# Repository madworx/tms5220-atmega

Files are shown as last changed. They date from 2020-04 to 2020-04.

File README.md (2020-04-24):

# TMS5220 Exploration unit

This project was created to try out the Texas Instruments TMS5220 _Voice synthesis processor_ (of TI99/4A, Apple II Echo 2, and various pinball/arcade games fame).

First off, a word of warning: The PCB being powered by potentially three sources (PSU, Communication USB, AVR ISP), I've observed some weird behavior with power unexpectedly flowing in the wrong direction, causing intermittent system interruptions, host USB-port lock-up requiring system restart and one burnt MCU.

Preferably disconnect the PSU before connecting the ISP and move the `J3` jumper to programming mode.

The project as it currently is is rather "build your own" but since the project was created to let me toy with the TMS5220 chip, it's not likely to see any major improvements in the forseeable future.

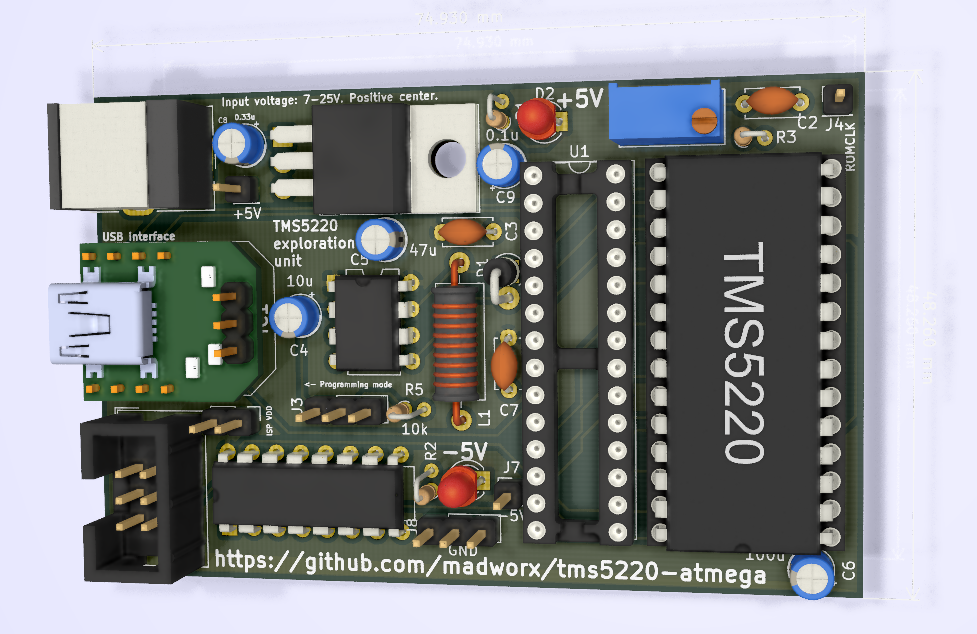
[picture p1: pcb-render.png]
PCB rendering


## Software environment

* `avrdude`
* `avr-gcc`

## Peripherials setup

### Programmer (AVR ISP)

I used a cheap `usbasp` clone.

### UB232R

The `UB232R` interface needs to be configured using the [FT_Prog] tool:

* `High Current I/O's` to be disabled.

* Under the `IO Controls` section, output on pin `C0` should be set to `CLK12`, providing the Atmega 328P with a system clock of 12MHz.

The baud rate is the USB interface is configured by the host operating system driver. The MCU UART baud rate need to be matched to this.

[FT_Prog]: https://www.ftdichip.com/Support/Utilities.htm#FT_PROG

### Atmega 328P

* `lfuse` should be programmed to _external clock without /8DIV_ (`0xE0`):

```
avrdude -p m328p -c usbasp -U lfuse:w:0xE0:m
```

## TMS5220 details

### D/A

10-bit twos-complement.

```
|           |  PC latice outputs                                      |            |             |
|-----------|---------------------------------------------------------|------------|-------------|
| Value     |  YD  YC  YB  YA  Y9  Y8  Y7  Y6  Y5  Y4  Y3  Y2  Y1  Y0 | D/A input  | Analog (uA) |
|-----------|---------------------------------------------------------|------------|-------------|
| > +127    |  0   1   1   x   x   x   x   x   x   x   x   x   x   x  |  11111111  |      0      |
| > +127    |  0   1   0   x   x   x   x   x   x   x   x   x   x   x  |  11111111  |      0      |
| > +127    |  0   0   1   x   x   x   x   x   x   x   x   x   x   x  |  11111111  |      0      |
| +127      |  0   0   0   1   1   1   1   1   1   1   1   x   x   x  |  11111111  |      0      |
| +126      |  0   0   0   1   1   1   1   1   1   1   0   x   x   x  |  11111110  |      5.86   |
| etc.      |  0   0   0   .   .   .   .   .   .   .   .   x   x   x  |  ........  |     .....   |
| +1        |  0   0   0   0   0   0   0   0   0   0   1   x   x   x  |  10000001  |    738.00   |
| 0         |  0   0   0   0   0   0   0   0   0   0   0   x   x   x  |  10000000  |    744.00   |
| -1 (off)  |  1   1   1   1   1   1   1   1   1   1   1   x   x   x  |  01111111  |    750.00   |
| -2        |  1   1   1   1   1   1   1   1   1   1   0   x   x   x  |  01111110  |    755.80   |
| etc.      |  1   1   1   .   .   .   .   .   .   .   .   x   x   x  |  ........  |   .......   |
| -128      |  1   1   1   0   0   0   0   0   0   0   0   x   x   x  |  00000000  |   1500.00   |
| < -128    |  1   1   0   x   x   x   x   x   x   x   x   x   x   x  |  00000000  |   1500.00   |
| < -128    |  1   0   1   x   x   x   x   x   x   x   x   x   x   x  |  00000000  |   1500.00   |
| < -128    |  1   0   0   x   x   x   x   x   x   x   x   x   x   x  |  00000000  |   1500.00   |
```

### Timing diagram

* `ROMCLK` = 160kHz (= 6,26uS = 75x 12MHz cycles -> 37.5 cycles per level):
* `T11` is pulled high before the start of each 10-bit word. (Note: The `T11`/`IO` cycle will run as long as the TMS chip is powered, regardless if any `SPEAK` or `SPEAK EXTERNAL` commands are currently running or not.)

```
 | 36| 36| 36| Clock cycles @ 12MHz

                             |
  ___     ___     ___     ___v    ___     ___     ___     ___     ___     ___     ___     ___     ___     
_|   |___|   |___|   |___|   |___|   |___|   |___|   |___|   |___|   |___|   |___|   |___|   |___|   |___|   *ROMCLK*
          _______            :
_________|       |___________:____________________________________________________________________________   *T11*
                          ___:___________________________________________________________________________
_________________________|  lsb  |       |       |       |       |       |       |       |       |  msb  |   *I/O*
                             ^
                             |
                             +-- This is where we sample & store the value of I/O.
```

## Code structure 

* TMS5220 flag us that it's ready to receive data with the use of the `~READY` signal.

* On negative edge trigger: Sample I/O pin, shift storage byte and add bit. (This should be in the range of ~15 instructions)

* On positive edge trigger: Perform state-based logic (max ~35 clock cycles to complete each operation).

* A full write of `DBUS` on the TMS requires us to write to three different ports on the Atmega. (~15 instructions each)

## Accessing the USB UART under linux with 250000 baud rate

```
 $ setserial -a /dev/ttyUSB0 spd_cust
 $ setserial -a /dev/ttyUSB0 divisor 64 # for 375000
 $ setserial -a /dev/ttyUSB0 divisor 96 # for 250000
 $ stty -F /dev/ttyUSB0 38400
 $ socat TCP-L:1147 FILE:/dev/ttyUSB0,b38400,raw,echo=0
```

## Afterthoughts on PCB design

* Atmega reset button on PCB would be nice.
* Proximity to other components makes the jumpers hard to access.
* Should have used a trimmer with lower resistance and a base resistor of higher value to enable more accurate tuning of `ROMCLK`.
* Possibly some form of "mode switch" to select different functions in the MCU.
* Could likely have been powered by USB directly, eliminating the external PSU. (However, need to take into account that +5 and -5V needs to be applied more or less simultaneous)
* Hard to dislodge the TMS chip due to resistor in the way.
* Bottom mounting of TMS resistor on PCB due to placement near socket edge -- has been fixed in current PCB layout, but not in manufactured ones.
* Hard to dislodge Atmega328P due to resistor in the way -- has been fixed in current PCB layout, but not in manufactured ones.
* A status LED or two would be nice.
* Reading more about the TMS chip, I could have driven the "TESTING USE ONLY" `PROMOUT` pin to -5 to enable external clocking, removing timing constraints for the MCU.
* The "programming mode" jumper in the end turned out quite useless -- a proper RESET of the TMS-chip usually cleared up any inconsistencies.
* Multiple pins connected to TMS5220 that in the end weren't needed.
* Power drainage is much higher than expected; Around 500mA and LM7805 reaches 51 degrees C.

## Oscillator caps

### TMS5220 T11, ROMCLK, IO

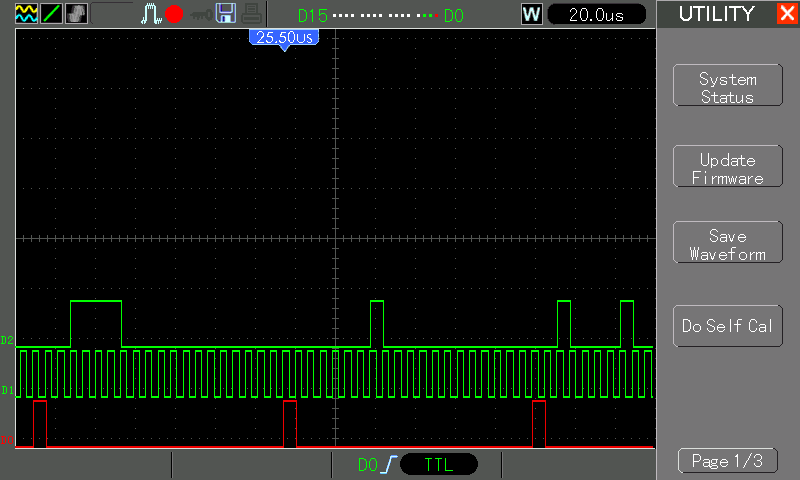
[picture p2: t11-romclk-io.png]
TMS5220 T11, ROMCLK, IO


### TMS5220 ROMCLK output

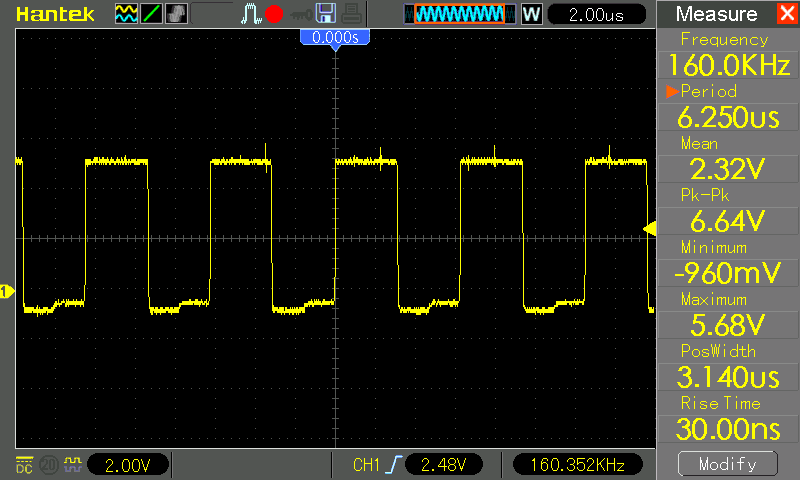
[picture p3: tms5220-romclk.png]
TMS5220 ROMCLK output


### UB232R-CLK12

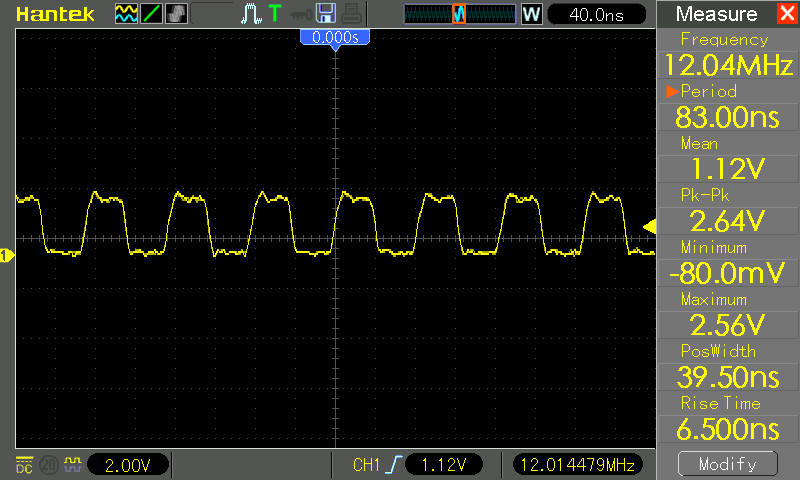
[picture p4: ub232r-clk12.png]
ub232r-clk12


Connected to Atmega328P:

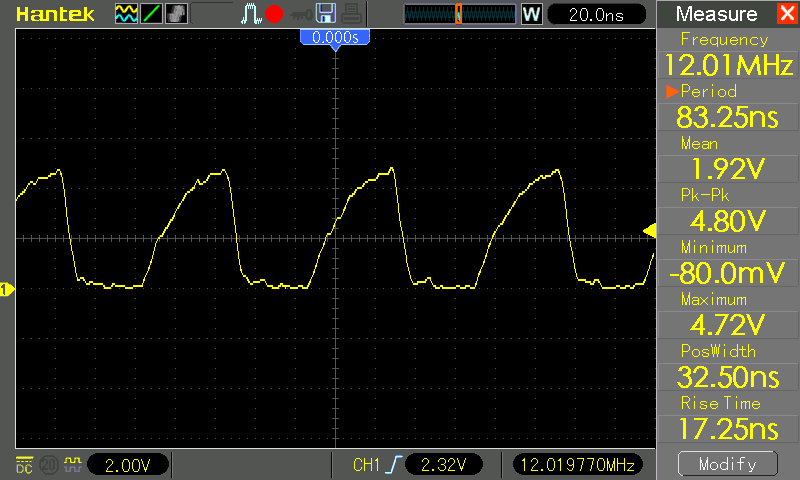
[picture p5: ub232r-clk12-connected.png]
ub232r-clk12-connected


## References

* [TMS5220 Data sheet PDF](references/tms5220.pdf)
* [TMS5220 reference from www.unige.ch](http://www.unige.ch/medecine/nouspikel/ti99/speech.htm)

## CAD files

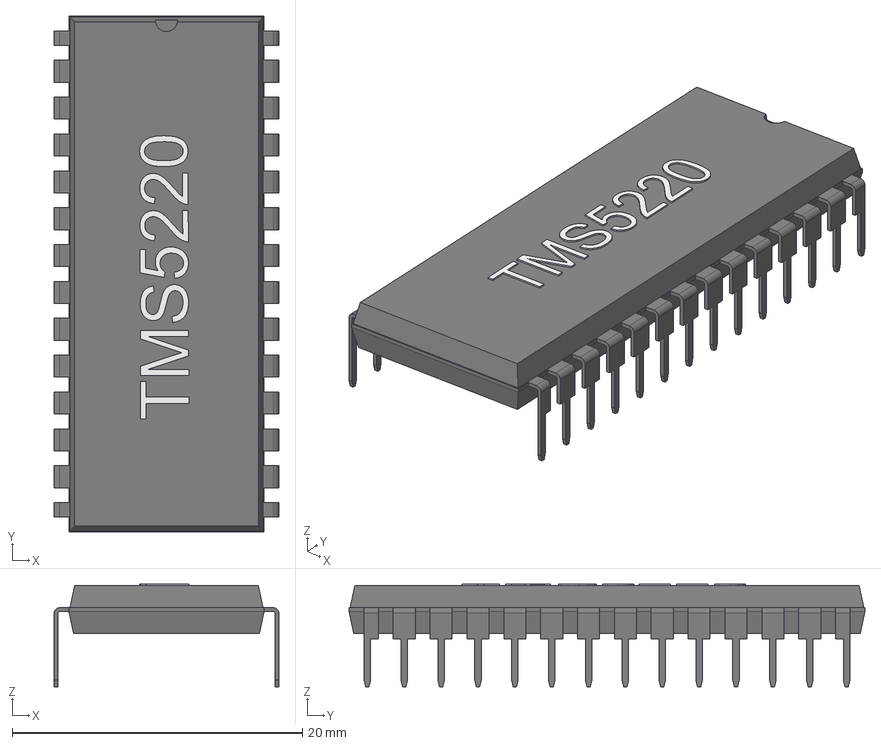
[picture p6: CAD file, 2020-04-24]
hardware/components/TMS5220.FCStd
15.5 x 35.6 x 7.08 mm
DIP-28_W15.24mm

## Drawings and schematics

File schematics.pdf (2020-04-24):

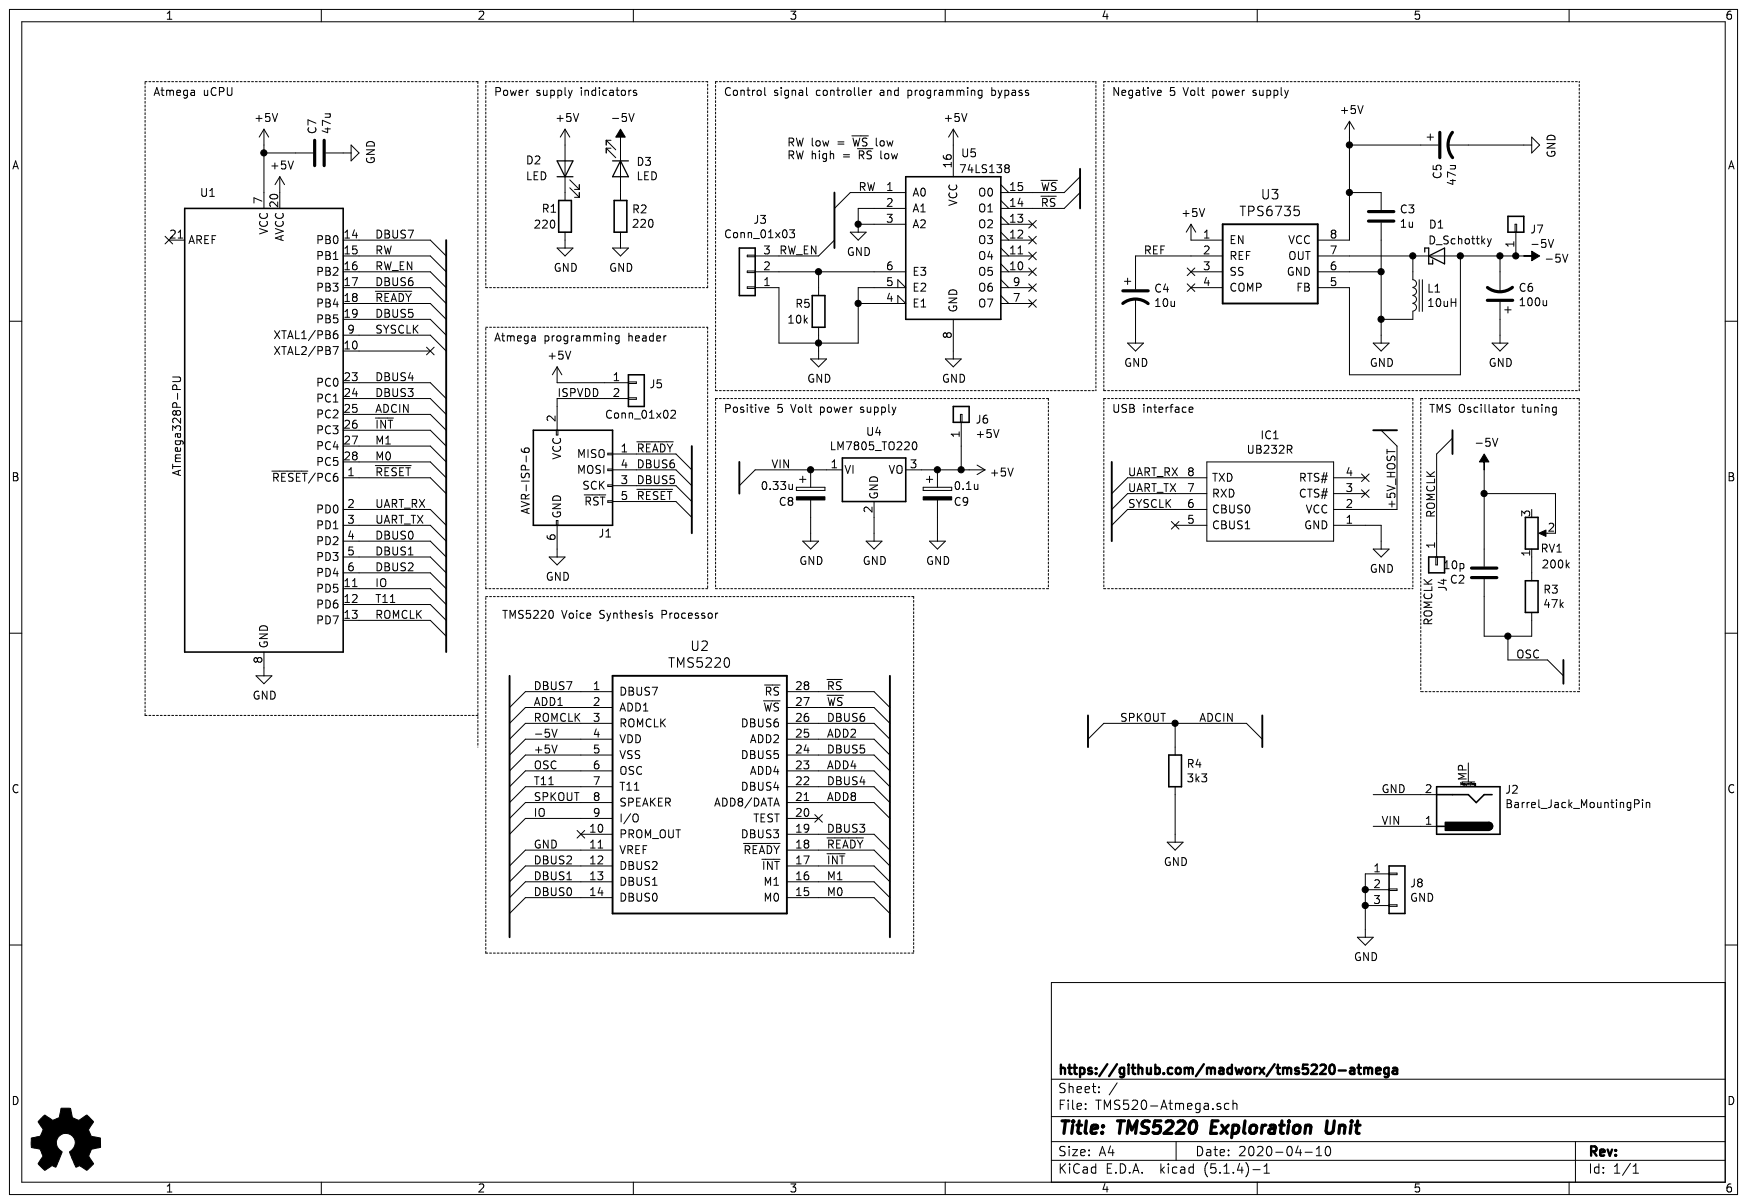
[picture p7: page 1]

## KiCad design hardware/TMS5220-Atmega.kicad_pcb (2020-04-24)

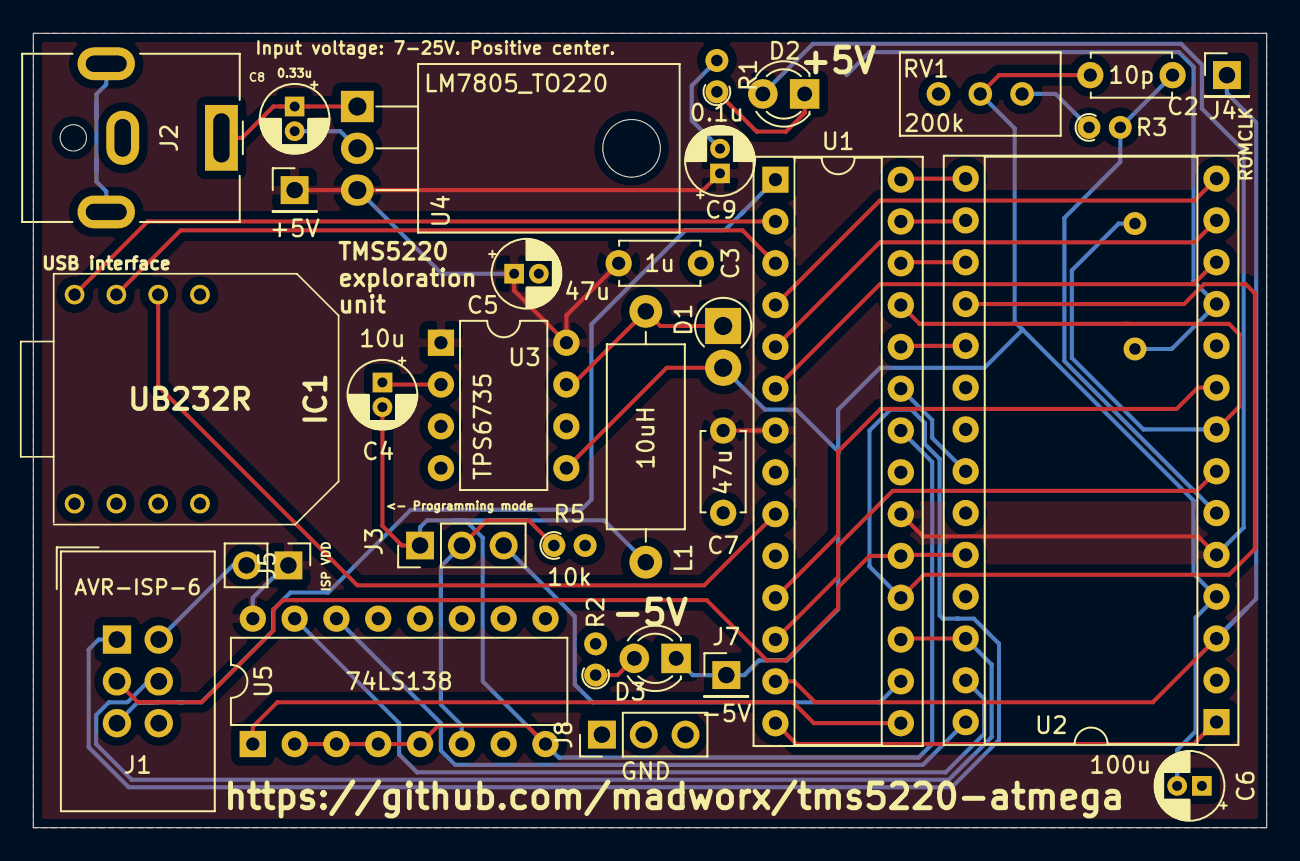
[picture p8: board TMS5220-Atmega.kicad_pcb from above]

Board: 2 copper layers, 74.9 x 48.3 mm, 32 parts (1 on the bottom side), 36 nets.

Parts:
C2: 10p; C_Disc_D4.7mm_W2.5mm_P5.00mm
C3: 1u; C_Disc_D4.7mm_W2.5mm_P5.00mm
C4: 10u; CP_Radial_D4.0mm_P1.50mm
C5: 47u; CP_Radial_D4.0mm_P1.50mm
C6: 100u; CP_Radial_D4.0mm_P1.50mm
C7: 47u; C_Disc_D4.7mm_W2.5mm_P5.00mm
C8: 0.33u; CP_Radial_D4.0mm_P1.50mm
C9: 0.1u; CP_Radial_D4.0mm_P1.50mm
D1: D_Schottky; D_DO-41_SOD81_P2.54mm_Vertical_AnodeUp
D2, D3: LED; LED_D3.0mm
IC1: UB232R
J1: AVR-ISP-6; IDC-Header_2x03_P2.54mm_Vertical
J2: Barrel_Jack_MountingPin; BarrelJack_CUI_PJ-063AH_Horizontal
J3: Conn_01x03; PinHeader_1x03_P2.54mm_Vertical
J4: ROMCLK; PinHeader_1x01_P2.54mm_Vertical
J5: Conn_01x02; PinHeader_1x02_P2.54mm_Vertical
J6: +5V; PinHeader_1x01_P2.54mm_Vertical
J7: -5V; PinHeader_1x01_P2.54mm_Vertical
J8: GND; PinHeader_1x03_P2.54mm_Vertical
L1: 10uH; L_Axial_L11.0mm_D4.5mm_P15.24mm_Horizontal_Fastron_MECC
R1, R2: 220; R_Axial_DIN0204_L3.6mm_D1.6mm_P1.90mm_Vertical
R3: 47k; R_Axial_DIN0204_L3.6mm_D1.6mm_P1.90mm_Vertical
R4: 3k3; R_Axial_DIN0204_L3.6mm_D1.6mm_P7.62mm_Horizontal
R5: 10k; R_Axial_DIN0204_L3.6mm_D1.6mm_P1.90mm_Vertical
RV1: 200k; Potentiometer_Bourns_3296W_Vertical
U1: ATmega328P-PU; DIP-28_W7.62mm_Socket
U2: TMS5220; DIP-28_W15.24mm_Socket
U3: TPS6735; DIP-8_W7.62mm
U4: LM7805_TO220; TO-220-3_Horizontal_TabDown
U5: 74LS138; DIP-16_W7.62mm

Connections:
+5V: C3.1, C5.1, C7.1, C9.1, D2.2, J5.1, J6.1, U1.7, U1.20, U2.5, U3.1, U3.8, U4.3, U5.16
-5V: C2.2, C6.2, D1.2, D3.1, J7.1, RV1.2, U2.4, U3.5
/ADCIN: R4.1, U1.25, U2.8
/DBUS0: U1.4, U2.14
/DBUS1: U1.5, U2.13
/DBUS2: U1.6, U2.12
/DBUS3: U1.24, U2.19
/DBUS4: U1.23, U2.22
/DBUS5: J1.3, U1.19, U2.24
/DBUS6: J1.4, U1.17, U2.26
/DBUS7: U1.14, U2.1
/IO: U1.11, U2.9
/ISPVDD: J1.2, J5.2
/M0: U1.28, U2.15
/M1: U1.27, U2.16
/OSC: C2.1, R3.2, U2.6
/REF: C4.1, U3.2
/ROMCLK: J4.1, U1.13, U2.3
/RW: U1.15, U5.1
/RW_EN: J3.3, U1.16
/SYSCLK: IC1.6, U1.9
/T11: U1.12, U2.7
/UART_RX: IC1.8, U1.2
/UART_TX: IC1.7, U1.3
/VIN: C8.1, J2.1, U4.1
/~INT: U1.26, U2.17
/~READY: J1.1, U1.18, U2.18
/~RESET: J1.5, U1.1
/~RS: U2.28, U5.14
/~WS: U2.27, U5.15
GND: C3.2, C4.2, C5.2, C6.1, C7.2, C8.2, C9.2, IC1.1, J1.6, J2.2, J3.1, J8.1, J8.2, J8.3, L1.2, R1.2, R2.2, R4.2, R5.2, U1.8, U1.22, U2.11, U3.6, U4.2, U5.2, U5.3, U5.4, U5.5, U5.8
unnamed: D1.1, L1.1, U3.7
unnamed: D2.1, R1.1
unnamed: D3.2, R2.1
unnamed: J3.2, R5.1, U5.6
unnamed: R3.1, RV1.1

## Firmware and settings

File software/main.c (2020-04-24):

#define F_CPU 12000000      /* 12 MHz */
#define BAUD    250000      /* 250'000 baud */

#define READY    PB4
#define RW_EN    PB2
#define RW       PB1
#define INT      PC3
#define T11      PD6
#define IO       PD5
#define ROMCLK   PD7

#define BIT_SET(x,y)    (x |= (1<<y))     /* Set bit y in byte x */
#define BIT_CLEAR(x,y)  (x &= (~(1<<y)))  /* Clear bit y in byte x */
#define BIT_GET(x,y)    (x & (1<<y))      /* Get bit y in byte x */

#include <avr/io.h>
#include <util/delay.h>
#include <stdio.h>

#include "lpc10.h"

static const uint8_t lookup[16] = {
  0x0, 0x8, 0x4, 0xc, 0x2, 0xa, 0x6, 0xe,
  0x1, 0x9, 0x5, 0xd, 0x3, 0xb, 0x7, 0xf
};

inline static uint8_t reverse(uint8_t n) {
   return (lookup[n&0b1111] << 4) | lookup[n>>4];
}

/**
 * Atmega 328P internal UART functions
 **/
inline void uart_init()
{
    unsigned int ubrr = F_CPU/16/BAUD-1;
    UBRR0H = (uint8_t)(ubrr >> 8);
    UBRR0L = (uint8_t)ubrr;
    UCSR0B = (1 << RXEN0) | (1 << TXEN0);
    UCSR0C = (0 << USBS0) | (3 << UCSZ00);
}
inline uint8_t uart_can_read(void) { return (UCSR0A & (1 << RXC0)); }
inline uint8_t uart_read(void) { return UDR0; }
inline uint8_t uart_can_write(void) { return (UCSR0A & (1 << UDRE0)); }
inline void uart_write(uint8_t data) { UDR0 = data; }
void uart_write_string(const uint8_t *str)
{
    while(*str)
    {
        while(!uart_can_write());
        uart_write(*str);
        str++;
    }
}


static void fail_abort(const uint8_t *s)
{
    uart_write_string("Abort: ");
    uart_write_string(s);
    uart_write_string("\r\n");
    while(1){}
}


/**
 * TMS5220 functions
 **/
inline uint8_t tms_is_ready() { return !BIT_GET(PINB, READY); }
inline uint8_t tms_is_interrupt() { return !BIT_GET(PINC, INT); }

inline void tms_wait_for_bitstream()
{
    while (!BIT_GET(PIND, T11));
    while (BIT_GET(PIND, T11));
    while (!BIT_GET(PIND, ROMCLK));
    while (BIT_GET(PIND, ROMCLK));
}
inline uint8_t tms_sample_io()
{
    /* In case our state_post_ functions returns while ROMCLK is still low;
     * wail until romclock is high and then low again. */
    while (!BIT_GET(PIND, ROMCLK));
    while (BIT_GET(PIND, ROMCLK));
    return BIT_GET(PIND, IO);
}
inline void tms_rw_write()
{
    BIT_CLEAR(PORTB, RW);
    BIT_SET(PORTB, RW_EN);
}
inline void tms_rw_read()
{
    BIT_SET(PORTB, RW);
    BIT_SET(PORTB, RW_EN);
}
inline void tms_rw_disable() 
{ 
    BIT_CLEAR(PORTB, RW_EN); 
}

uint8_t lookup_b[256];
uint8_t lookup_c[256];
uint8_t lookup_d[256];

void generate_dbus_lookup_tables() {
    uint8_t v = 0;
    do {
        v--;
        lookup_b[v] = (v & (1 << 0)) >> (0 - 0)    // BIT0 -> PB0
                      | (v & (1 << 1)) << (3 - 1)  // BIT1 -> PB3
                      | (v & (1 << 2)) << (5 - 2); // BIT2 -> PB5
        lookup_c[v] = (v & (1 << 4)) >> (4 - 1)    // BIT4 -> PC1
                      | (v & (1 << 3)) >> (3 - 0); // BIT3 -> PC0
        lookup_d[v] = (v & (1 << 7)) >> (7 - 2)    // BIT7 -> PD2
                      | (v & (1 << 6)) >> (6 - 3)  // BIT6 -> PD3
                      | (v & (1 << 5)) >> (5 - 4); // BIT5 -> PD4
    } while(v);
}

inline void tms_dbus_write_port_b(uint8_t v)
{
    PORTB = (PORTB & 0b11010110) | lookup_b[v];
}

inline void tms_dbus_write_port_c(uint8_t v)
{
    PORTC = (PORTC & 0b11111100) | lookup_c[v];
}

inline void tms_dbus_write_port_d(uint8_t v)
{
    PORTD = (PORTD & 0b11100011) | lookup_d[v];
}

void tms_dbus_issue_command(uint8_t v)
{
    tms_rw_disable();
    while (!tms_is_ready()); /* wait until TMS is ready */
    tms_dbus_write_port_b(v);
    tms_dbus_write_port_c(v);
    tms_dbus_write_port_d(v);
    tms_rw_write();
    while (tms_is_ready());  /* wait until TMS has picked up the command. */
    while (!tms_is_ready()); /* wait for operation completion. */
    tms_rw_disable();
}

/**
 * Reset TMS5220 chip.
 * Official power-up clear calls for 9x 0xFF followed by RESET command (X111XXXX).
 **/
void tms_issue_powerup_clear()
{
    for (uint8_t i = 0; i < 10; i++) {
        tms_dbus_issue_command(0xFF);
    	_delay_ms(20);
    }
}

/**
 * Issue SPEAK EXTERNAL command on TMS5220.
 **/
void tms_issue_spkext()
{
    tms_dbus_issue_command(reverse(0b00000110));
    _delay_ms(20);
}


/**
 * State- and temporary data variables.
 **/

/* Tracks our current read- and write-state. */
uint8_t read_state = 0x00;
uint8_t write_state = 0x00;

unsigned int num_read = 0x00;

uint8_t read_buffer = 0x00;
uint8_t write_buffer = 0x00;
uint8_t write_buffer_high = 0x00;


/**
 * Sample current bit value on the T11 pin and shift onto write_buffer.
 **/
void do_state_sample()
{
    write_buffer <<= 1;
    write_buffer |= tms_sample_io() ? 0x01 : 0x00;
}

void do_state_post_t11()
{
    if (write_state)
    {
        if (uart_can_write())
        {
            uart_write(write_buffer);
            write_buffer = 0x00;
        } else fail_abort("t11(): Could not write UART.");
    } // else noop
}

void do_state_post_d0()
{
    if (read_state == 1)
    {
        if (tms_is_ready())
        {
            if ( 0 ) {
                if (uart_can_read())
                {
                    read_buffer = uart_read();
                    read_state++;
                    /* num_read++; */ /* moved to do_state_post_d1() */
                }
            }
            else 
            {
                if (num_read < sizeof(lpc10))
                {
                    read_buffer = lpc10[num_read++];
                    read_state++;
                }
            } // else noop
        } // else noop
    } // else noop
}

void do_state_post_d1()
{
    if (read_state == 2)
    {
        num_read++; /* Moved from do_state_post_d0 to even out timing. */
        tms_rw_disable();
        read_state++;
    } // else noop
}

void do_state_post_d2()
{
    if (read_state == 3)
    {
        tms_dbus_write_port_b(read_buffer);
    } // else noop
}

void do_state_post_d3()
{
    if (read_state == 3)
    {
        tms_dbus_write_port_c(read_buffer);
    } // else noop
}

void do_state_post_d4()
{
    if (read_state == 3)
    {
        tms_dbus_write_port_d(read_buffer);
    } // else noop
}

void do_state_post_d5()
{
    if (read_state == 3)
    {
        tms_rw_write(); /* Instruct TMS to read data from DBUS. */
        read_state = 1;
    } // else noop
}

void do_state_post_d6()
{
    // do_state_post_d0();
}

void do_state_post_d7()
{
    write_buffer_high = write_buffer;
    write_buffer = 0x00;
    write_state = 1;
}

void do_state_post_d8()
{
    if (uart_can_write())
    {
        uart_write(write_buffer_high);
    } else fail_abort("d8(): Could not write UART.");
}

char buf[16];
void do_state_post_d9()
{
    if ( 1 )
    {
        /* Check for ~INT after we've filled the FIFO. */
        if ( tms_is_interrupt() && num_read > 12 ) 
        {
            snprintf(buf, 15, "INT@%i[%02x]", num_read, read_buffer);
            fail_abort(buf);
        }
    }
}


void setup_ports_direction()
{
	/* 0 = Input, 1 = Output */
	DDRB = 0b00101111;  /* [lsb->msb] DBUS7, RW, RW_EN, DBUS6, ~READY, DBUS5, SYSCLK, N/C */
	DDRC = 0b00000011;  /* [lsb->msb] DBUS4, DBUS3, ADCIN, ~INT, M1, M0, ~RESET */
	DDRD = 0b00011110;  /* [lsb->msb] UART_RX, UART_TX, DBUS0, DBUS1, DBUS2, IO, T11, ROMCLK */
}

int main(void)
{
    generate_dbus_lookup_tables();
    setup_ports_direction();
    tms_rw_disable();
    uart_init();
    tms_issue_powerup_clear();
    read_state = 1;

    while(!uart_can_read()); /* Wait for "start-command". */

    tms_issue_spkext();

    do {
        tms_wait_for_bitstream();
        do_state_post_t11();
        do_state_sample(); do_state_post_d0();
        do_state_sample(); do_state_post_d1();
        do_state_sample(); do_state_post_d2();
        do_state_sample(); do_state_post_d3();
        do_state_sample(); do_state_post_d4();
        do_state_sample(); do_state_post_d5();
        do_state_sample(); do_state_post_d6();
        do_state_sample(); do_state_post_d7();
        do_state_sample(); do_state_post_d8();
        do_state_sample(); do_state_post_d9();
    } while(1);
}
